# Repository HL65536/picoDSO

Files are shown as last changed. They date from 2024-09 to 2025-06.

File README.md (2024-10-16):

# picoDSO
================

**Open-Source Oscilloscope based on the Raspberry Pi Pico**

## Project Status
---------------

The minimum viable product is ready, and development of new features is 
ongoing. Updates will be published regularly, although the pace may be 
slow.

## Key Features
--------------

* **Flexible Data Acquisition**: Use either the internal ADC(s) of the 
Raspberry Pi Pico to measure up to ~2MSa/s or 1-2 faster external ADCs 
(requires a custom PCB) for >50MSa/s at 8 bit.
* **Optional PCB**: The project can be built on a breadboard or with an 
optional PCB for easier assembly and improved performance.
* **Display Options**: Supports both SSD1306 and ST7789 displays, with 
potential support for more in the future.

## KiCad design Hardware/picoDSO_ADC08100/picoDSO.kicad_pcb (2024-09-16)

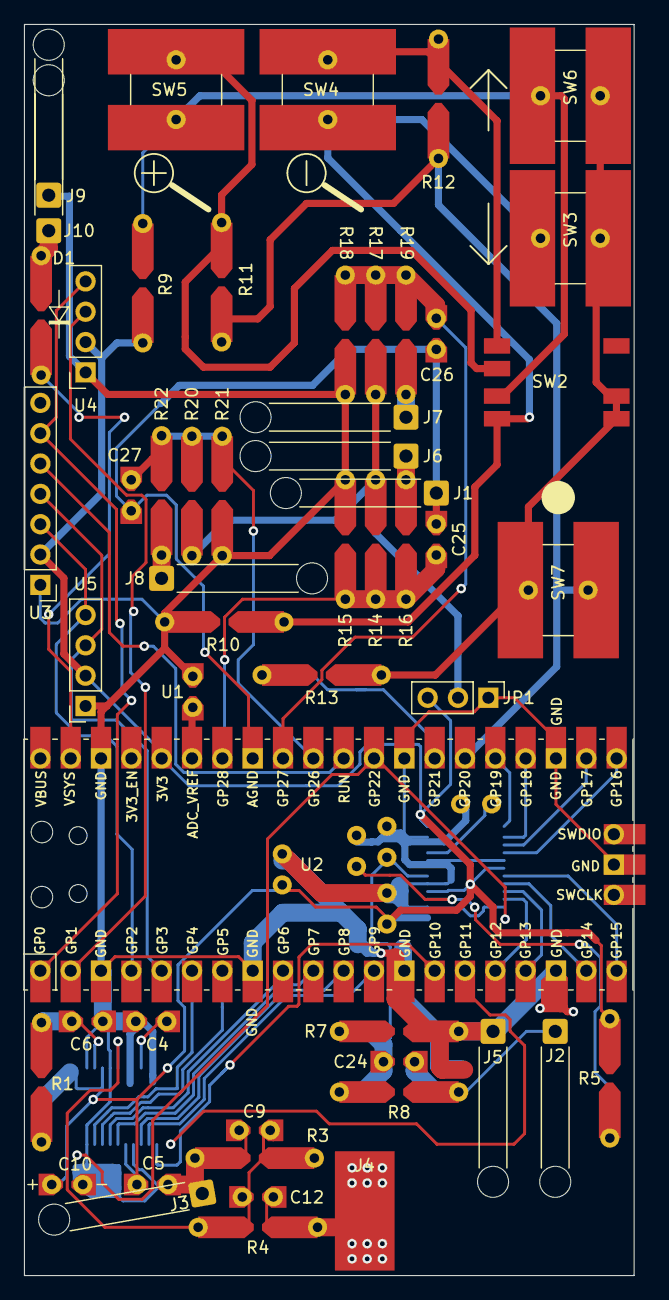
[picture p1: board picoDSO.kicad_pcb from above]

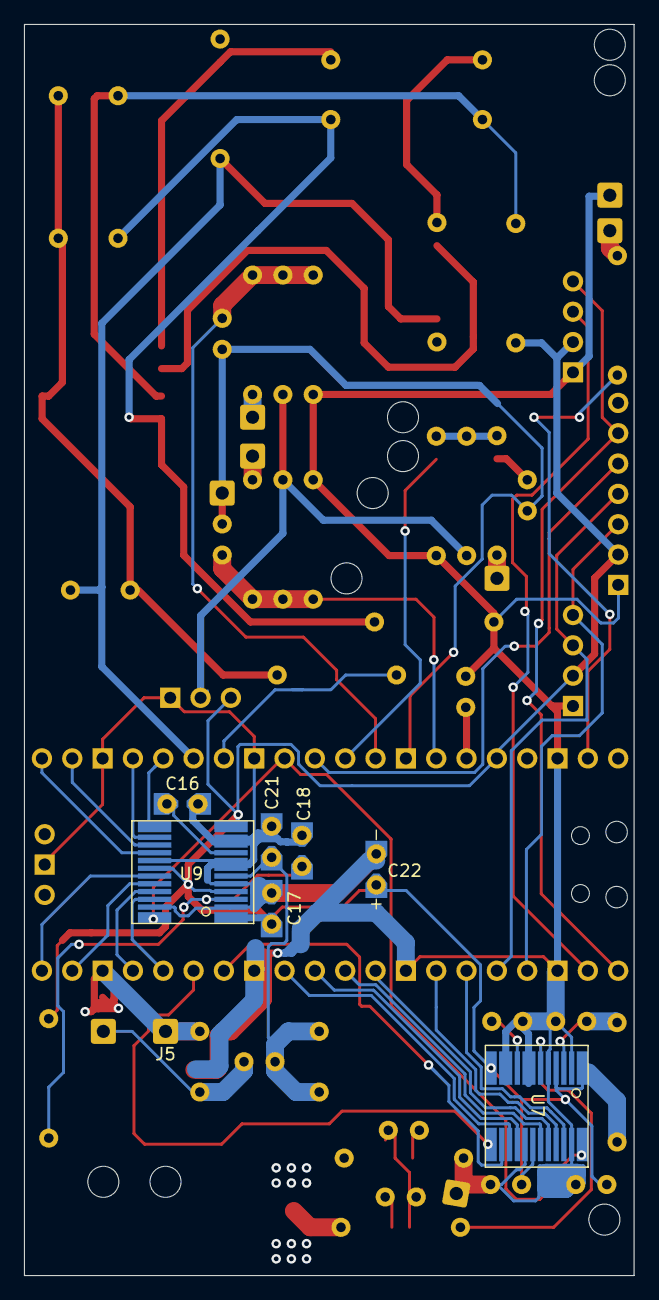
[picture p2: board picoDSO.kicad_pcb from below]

Board: 2 copper layers, 51.1 x 104.8 mm, 60 parts (7 on the bottom side), 50 nets.

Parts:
C4, C5, C6, C16, C17, C18: 100nF; universalMixed
C9, C21: Cdiv_bot; universalMixed
C10, C22: C_Polarized; universalMixedElectrolyticCap
C12, C24: Cdiv_top; universalMixed
C25, C26, C27: 68pF; universalMixed
D1: D_Schottky; universalMixedDiode
J1: internalADC_GND; SolderWire-0.5sqmm_1x01_D0.9mm_OD2.1mm_Relief
J2: chip1_probe+; SolderWire-0.5sqmm_1x01_D0.9mm_OD2.1mm_Relief
J3, J5: probeGND; SolderWire-0.5sqmm_1x01_D0.9mm_OD2.1mm_Relief
J4: chip0_probe+; SolderWirePad_1x01_SMD_5x10mm
J6, J7, J8: probeConnector; SolderWire-0.5sqmm_1x01_D0.9mm_OD2.1mm_Relief
J9: bat_GND; SolderWire-0.5sqmm_1x01_D0.9mm_OD2.1mm_Relief
J10: bat+; SolderWire-0.5sqmm_1x01_D0.9mm_OD2.1mm_Relief
JP1: internalADC_rangeselJumper; PinHeader_1x03_P2.54mm_Vertical
R1, R5: R; universalMixedLong
R3, R7: Rdiv_bot; universalMixedLong
R4, R8: Rdiv_top; universalMixedLong
R9, R10: 470; universalMixedLong
R11, R12: 4.7k; universalMixedLong
R13: 1k; universalMixedLong
R14, R15, R17, R18, R20, R21: 22k; universalMixedLong
R16, R19, R22: 100k; universalMixedLong
SW2: JoystickSwitch
SW3: dir2_alt; universalButton
SW4: dir4_alt; universalButton
SW5: dir3_alt; universalButton
SW6: dir1_alt; universalButton
SW7: button; universalButton
U1: optional_externalVREF; universalMixed
U2: Pico; RPi_Pico_SMD_TH
U3: ST7789; PinHeader_1x07_P2.54mm_Vertical
U4: SSD1306_Display1; PinSocket_1x04_P2.54mm_Vertical
U5: SSD1306_Display2; PinSocket_1x04_P2.54mm_Vertical
U7, U9: ADC08060; TSSOP-24 hand solder

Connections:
+3V3: C5.1, C10.1, C17.1, C22.1, JP1.3 (B), R1.2, R5.2, R9.1, U2.36 (3V3), U3.2 (VCC), U4.2 (VCC), U5.2 (VCC), U7.1 (AVDD), U7.4 (AVDD), U7.12 (AVDD), U7.18 (DVDD), U9.1 (AVDD), U9.4 (AVDD), U9.12 (AVDD), U9.18 (DVDD)
+BATT: D1.2 (A), J10.1
/ADC_chip0/clk: U2.29 (GPIO22), U7.24 (CLK), U9.24 (CLK)
/ADC_chip0/p0: U2.6 (GPIO4), U7.22 (D7)
/ADC_chip0/p1: U2.7 (GPIO5), U7.21 (D6)
/ADC_chip0/p2: U2.9 (GPIO6), U7.20 (D5)
/ADC_chip0/p3: U2.10 (GPIO7), U7.19 (D4)
/ADC_chip0/p4: U2.11 (GPIO8), U7.16 (D3)
/ADC_chip0/p5: U2.12 (GPIO9), U7.15 (D2)
/ADC_chip0/p6: U2.14 (GPIO10), U7.14 (D1)
/ADC_chip0/p7: U2.15 (GPIO11), U7.13 (D0)
/ADC_chip0/probe+: C12.1, J4.1, R4.1
/ADC_chip1/p0: U2.16 (GPIO12), U9.22 (D7)
/ADC_chip1/p1: U2.17 (GPIO13), U9.21 (D6)
/ADC_chip1/p2: U2.19 (GPIO14), U9.20 (D5)
/ADC_chip1/p3: U2.20 (GPIO15), U9.19 (D4)
/ADC_chip1/p4: U2.21 (GPIO16), U9.16 (D3)
/ADC_chip1/p5: U2.22 (GPIO17), U9.15 (D2)
/ADC_chip1/p6: U2.24 (GPIO18), U9.14 (D1)
/ADC_chip1/p7: U2.25 (GPIO19), U9.13 (D0)
/ADC_chip1/probe+: C24.1, J2.1, R8.1
/internalADCinput0/ADCpin: C27.1, R20.2, R21.1, R22.2, U2.31 (GPIO26_ADC0)
/internalADCinput1/ADCpin: C26.1, R17.2, R18.1, R19.2, U2.32 (GPIO27_ADC1)
/internalADCinput2/ADCpin: C25.1, R14.2, R15.1, R16.2, U2.34 (GPIO28_ADC2)
/navButtons/pin1: R13.1, U2.27 (GPIO21)
/navButtons/pin2: R11.2, R12.1, SW7.2, U2.26 (GPIO20)
GND: C4.2, C5.2, C6.2, C9.2, C10.2, C16.2, C17.2, C18.2, C21.2, C22.2, J3.1, J5.1, J9.1, JP1.1 (A), R3.2, R7.2, R10.2, R15.2, R18.2, R21.2, U1.2 (A), U2.3 (GND), U2.8 (GND), U2.13 (GND), U2.18 (GND), U2.23 (GND), U2.28 (GND), U2.38 (GND), U2.42 (GND), U3.1 (GND), U4.1 (GND), U5.1 (GND), U7.2 (AGND), U7.5 (AGND), U7.7 (VIN_GND), U7.8 (DGND), U7.10 (VRB), U7.11 (AGND), U7.17 (DGND), U7.23 (PWR_DWN), U9.2 (AGND), U9.5 (AGND), U9.7 (VIN_GND), U9.8 (DGND), U9.10 (VRB), U9.11 (AGND), U9.17 (DGND), U9.23 (PWR_DWN)
GNDA: C25.2, C26.2, C27.2, J1.1, U2.33 (AGND)
unnamed: C4.1, U7.9 (VRB)
unnamed: C6.1, R1.1, U7.3 (VRT)
unnamed: C9.1, C12.2, R3.1, R4.2, U7.6 (AIN)
unnamed: C16.1, U9.9 (VRB)
unnamed: C18.1, R5.1, U9.3 (VRT)
unnamed: C21.1, C24.2, R7.1, R8.2, U9.6 (AIN)
unnamed: D1.1 (K), U2.39 (VSYS)
unnamed: J6.1, R16.1
unnamed: J7.1, R19.1
unnamed: J8.1, R22.1
unnamed: R9.2, SW2.3 (1&3), SW5.1, SW6.1
unnamed: R10.1, SW2.4 (2&4), SW3.1, SW4.1
unnamed: R11.1, SW2.2 (dir3), SW5.2
unnamed: R12.2, SW2.1 (dir4), SW4.2
unnamed: R13.2, SW2.5 (dir2), SW2.6 (dir1), SW3.2, SW6.2, SW7.1
unnamed: U1.1 (K), U2.35 (ADC_VREF)
unnamed: U2.1 (GPIO0), U3.6 (DC), U4.4 (SDA)
unnamed: U2.2 (GPIO1), U4.3 (SCL)
unnamed: U2.4 (GPIO2), U3.3 (CLK), U5.4 (SDA)
unnamed: U2.5 (GPIO3), U3.4 (DAT), U5.3 (SCL)
unnamed: U2.30 (RUN), U3.5 (RES)
internalADCrangeSel: JP1.2 (C), R14.1, R17.1, R20.1

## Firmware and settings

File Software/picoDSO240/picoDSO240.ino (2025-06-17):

#include "rp2040Tools.h"
#include "EmbedUI.h"
#include "metric.h"
#include "oscilloscopeUtils.h"
#include "joystickButtons.h"
#include "pioRecorderDynamic.h"
#include "DisplayST7789_framebuf_2bit.h"


#define DISPLAY_WHITE 3
#define DISPLAY_COLOR1 1
#define DISPLAY_COLOR2 2
#define DISPLAY_BLACK 0

constexpr i32 highestIndexADCclock = 5;
enum ADCclock : i32
{
    clock250kSa = 0,
    clock500kSa = 1,
    clock1MSa = 2,
    clock2MSa = highestIndexADCclock - 2,
    clock2_5MSa = highestIndexADCclock - 1,
    clock3MSa = highestIndexADCclock
};
u32 clkSelectionsExt[] = {
    [0] = 40000,//24000,
    [1] = 80000,//48000,
    [2] = 120000,//96000,
    [highestIndexADCclock - 2] = 160000,//96000 * 2,
    [highestIndexADCclock - 1] = 200000,//9600 * 25,
    [highestIndexADCclock] = 240000//96000 * 3
    };

u32 clkSelectionsInt[] = {
    [0] = 24000,
    [1] = 48000,
    [2] = 96000,
    [highestIndexADCclock - 2] = 96000 * 2,
    [highestIndexADCclock - 1] = 9600 * 25,
    [highestIndexADCclock] = 96000 * 3
    };
//DisplayST7789_2bit display1(21,20,19,18,17,16,22,20);//breadboard version
DisplayST7789_2bit display1(0,17,3,2,-1,-1,-1,16);//PCB version 1.0 with only ADC chip 0
DisplayCommon &displayMenu = display1;
DisplayCommon &displayGraph = display1;
Adafruit_GFX &gfxMenu = display1.getGFX();
Adafruit_GFX &gfxGraph = display1.getGFX();

//JoystickButtons buts(1,0,2);//breadboard version
JoystickButtons buts(20,21);//PCB version 1.0


/*const String settingADCclockString[] = {"speed:\n"
                                        "160 kSa/s\n"
                                        "250 kSa/s\n"
                                        "500 kSa/s\n"
                                        "  2 MSa/s\n"
                                        "2.5 MSa/s\n"
                                        "  3 MSa/s"};
SettingEnum settingADCclock(settingADCclockString);*/
#define GRAPH_HEIGHT 128
#define GRAPH_WIDTH 240
#define GRAPH_HEIGHT_OFFSET 112

#define DATABUF_SIZE 200000l

Recording recording;//for now only one single recording is saved at a time, may be changed in the future
volatile bool useExternal=true;
volatile i32 captureIndex=-1;

volatile u8 channelCount=1;

bool startScreen = true;
bool onlyPositiveVoltageRange;
bool noInputStage=false;

u16 channelColors[]=//size must be at least equal to channelCount
{
    DISPLAY_COLOR1,
    DISPLAY_COLOR2
};

ADCclock ADCclockSelection = clock1MSa;

u32 clkWanted;

u32 adcClkDivInfo=4;//96 for internal ADC, auto-set later!

void settingsScreenLoop()
{
    displayMenu.startDrawing(1);
    buts.evaluate();
    if(buts.getButtonEvent())
    {
        recording.allocateSpace(DATABUF_SIZE,channelCount);
        startScreen=false;
    }
    else
    {
        ADCclockSelection = (ADCclock)(((i32)ADCclockSelection) + buts.getUpEvents());
        if (ADCclockSelection > highestIndexADCclock)
        {
            ADCclockSelection = (ADCclock)0;
        }
        if (ADCclockSelection < 0)
        {
            ADCclockSelection = (ADCclock)highestIndexADCclock;
        }
        gfxMenu.print("speed: ");
        adcClkDivInfo = useExternal?4:96;
        u32 kSa = clkSelectionsExt[ADCclockSelection] / adcClkDivInfo;
        gfxMenu.print(kSa);
        gfxMenu.println("kSa/s");

        gfxMenu.println();
        gfxMenu.println("press .");
        gfxMenu.println("  to");
        gfxMenu.println("confirm");
        gfxMenu.println("settings");

        displayMenu.endDrawing();
    }
    
}
void setup()
{
    pinMode(LED_BUILTIN, OUTPUT);
    display1.Init();
    display1.setRotation(2);
    while(startScreen)
    {
        settingsScreenLoop();
    }
}
u8 highFor2Vref=14;
u8 refSelLowIsInternal=15;
void setup1()//2nd core
{
    pinMode(LED_BUILTIN, OUTPUT);

    pinMode(A0, INPUT);
    pinMode(A1, INPUT);
    pinMode(A2, INPUT);

    pinMode(highFor2Vref,OUTPUT);
    digitalWrite(highFor2Vref,HIGH);

    pinMode(refSelLowIsInternal, OUTPUT);
    digitalWrite(refSelLowIsInternal, LOW);

    while(startScreen)
    {
        delay(1);
    }

    clkWanted = clkSelectionsExt[ADCclockSelection];
    if (ADCclockSelection == clock500kSa)
    {
        setCPUClockspeed(133000); // max speed by specs
        delay(100);
    }
    else
    {
        if (clkWanted > 200000)
        {
            setCoreVoltageOffset(4);
            delay(100);
        }
        else if (clkWanted > 180000)
        {
            setCoreVoltageOffset(2);
            delay(100);
        }
        setADCclockBoundToCPUclock(true); // ADC now at adcClock/96000 MSa/s
        setCPUClockspeed(clkWanted);
    }
}

float scaleTime = 1024;
u32 discardSamples = 64;// don't show the first 64 samples to avoid showing ADC startup glitches
u32 startPos = discardSamples;

void printPIOdebugInfo()
{
    gfxMenu.print("PIO rx FIFO lvl: ");
    gfxMenu.print(pio_sm_get_rx_fifo_level(pio0, 0));
    gfxMenu.print("; TX: ");
    gfxMenu.print(pio_sm_get_tx_fifo_level(pio0, 0));
    gfxMenu.print("; stall: ");
    gfxMenu.println(pio_sm_is_exec_stalled(pio0, 0));
    gfxMenu.print("PIO PC: ");
    for(u32 i=0;i<8;i++)
    {
        gfxMenu.print(pio_sm_get_pc(pio0, 0));
        gfxMenu.print('|');
    }
    gfxMenu.println();
}

float convertVoltage(u16 rawValue,bool onlyPositive=true)
{
    float ret=rawValue;
    if (recording.is16bit())
    {
        ret /= 4096.0f;//only supported ADC with 16 bit data length is currently the internal 12-bit ADC
    }
    else
    {
        ret /= 256.0f;
    }
    if(!onlyPositive)
    {
        ret-=0.5f;
    }
    ret *= 15;//(3.00f * 11.0f);//3.27V default reference, 11:1 voltage divider
    return ret;
}
bool err=false;
bool unconv=false;
volatile i8 samplesInFIFO = 0;
float tuningFactor=1;
LoopTimer lt;


u16 instr0;
u16 instr1;
u32 instrS;

void loop()
{
    float time=lt.tick();
    
    u32 dataLength = recording.getNumSamples()-discardSamples;
    if(recording.getNumSamples()<discardSamples+1)
    {
        delay(1);
        return;
    }
    //dataToDisplay[0]^=65536/4;//fake an unconverged sample in 1/2 of the frames
    buts.evaluate();
    i8 upDir=buts.getUpEvents();
    if(upDir>0)
    {
        scaleTime/=2;
    }
    else if(upDir<0)
    {
        scaleTime *= 2;
    }
    i8 rightDir=buts.getRightEvents();
    startPos += scaleTime * 32 * rightDir; // auto-protects against underflow
    if (startPos >= dataLength)
    {
        startPos = dataLength - 1;
    }
    if (startPos < discardSamples)
    {
        startPos = discardSamples;
    }

    displayMenu.startDrawing(1);

    BandwidthExtenderRC bwExt(((1000000.0f*adcClkDivInfo) / clkSelectionsExt[ADCclockSelection]), 26, 10, tuningFactor);//224pF (theoret. 236pF) for P11, 84pF für Bernd, 26pF for P11.2
    u16 voltMax = 0;
    u16 voltMin = 4096;
    for (u32 i = 0; i < dataLength; i++) // find highest + lowest measured voltage
    {
        u16 rawVal = recording.readIndex(i);//get the value from memory only once, as this prevents a previous bug of the value being changed by the DMA in between the statements below
        u16 rawValMasked = rawVal & 4095; //filter out unconverged flag
        if (rawVal != rawValMasked)
        {
            unconv = true;
        }
        if (rawValMasked < voltMin)
        {
            voltMin = rawValMasked;
        }
        if (rawValMasked > voltMax)
        {
            voltMax = rawValMasked;
        }
    }
    float scaleAdd = -float(voltMin);
    float scaleDiv = float(voltMax - voltMin);
    if (scaleDiv < 1)
    {
        scaleDiv = 1; //prevent /0
    }
    GraphDisplaySpace gds(GRAPH_HEIGHT, GRAPH_WIDTH);
    //i32 lastIndex = -1;
    gfxGraph.fillScreen(ST77XX_BLACK); // Fill screen with black color
    gfxGraph.setCursor(0, 0);          // Set cursor to top-left corner;

    for (i32 i = 0; i < GRAPH_WIDTH; i++)
    {
        i32 index = i * scaleTime + startPos;
        if (index < 0)
        {
            continue;
        }
        if (index >= dataLength)
        {
            continue;
        }
        for (u8 ch = 0; ch < channelCount; ch++)
        {
            u16 rawVal = recording.readIndex(index,ch);
            float voltage = rawVal & 4095; // filter out unconverged flag
                /*if (index == lastIndex)
                {
                    voltage = lastVoltage;
                }
                else if (scaleTime<5)
                {
                    u32 increments = index - lastIndex;
                    i32 bwX = ~(i32(0));
                    for (u32 i = 0; i < increments; i++)
                    {
                        bwX = bwExt.calcStep(dataToDisplay[lastIndex + i] & 4095);
                    }
                    if (bwX != ~(i32(0)))
                    {
                        voltage = bwX / 65536.0f;
                    }
                }
                lastVoltage = voltage;*/
            voltage += scaleAdd;
            voltage /= scaleDiv;
            u16 pixY = gds.toY(voltage);
            //u16 color = channelColors[ch];
            if (pixY == -1)
            {
                continue;
            }
            if (rawVal >= 4096)
            {
                gfxGraph.drawPixel(i, pixY - 1, DISPLAY_COLOR1); // mark unconverged sample
                gfxGraph.drawPixel(i, pixY + 1, DISPLAY_COLOR1);
            }
            gfxGraph.drawPixel(i, pixY + GRAPH_HEIGHT_OFFSET, DISPLAY_COLOR2);
        }
    }
        
    if (captureIndex == -1)
    {
        gfxMenu.println("Press . for capture");
    }
    else
    {
        gfxMenu.print(captureIndex);
        gfxMenu.print('/');
        gfxMenu.println(recording.is16bit()? DATABUF_SIZE/2:DATABUF_SIZE);
    }
    gfxMenu.print("top:    ");
    metricPrintln(convertVoltage(voltMax, onlyPositiveVoltageRange), 'V', gfxMenu, 4);
    gfxMenu.print("bottom: ");
    metricPrintln(convertVoltage(voltMin, onlyPositiveVoltageRange), 'V', gfxMenu, 4);
    gfxMenu.print(startPos);
    gfxMenu.print("; ");
    gfxMenu.print("timespan: ");
    float timePerSample = (adcClkDivInfo* 1000.0f/clkSelectionsExt[ADCclockSelection]) / 1000.0f / 1000.0f;
    metricPrintln(timePerSample * scaleTime * GRAPH_WIDTH, 's', gfxMenu, 4);
    if (err)
    {
        gfxMenu.println("error capturing");
    }
    if (unconv)
    {
        gfxMenu.println("unconverged samples");
    }
    gfxMenu.print("raw min: ");
    gfxMenu.println(voltMin);
    gfxMenu.print("raw max: ");
    gfxMenu.println(voltMax);
    gfxMenu.print("tuning: ");
    gfxMenu.println(tuningFactor);
    gfxMenu.print("clk: ");
    gfxMenu.println(getCPUClockspeed() / 1000000.0f);
    printPIOdebugInfo();
    metricPrintln(time, 's', gfxMenu);
    gfxMenu.print(instr0, HEX);
    gfxMenu.print(' ');
    gfxMenu.print(instr1, HEX);
    gfxMenu.print(' ');
    gfxMenu.println(instrS);
    // displayMenu.print("corrMtp: ");
    // displayMenu.println(bwExt.correctionMultiplier);

    // displayGraph.display();
    displayMenu.endDrawing();

}
bool capturePIOcombined(u8 startPin, u8 clkPin)
{
    digitalWrite(LED_BUILTIN,HIGH);
    u8 dataBits = 8*channelCount;
    for (u8 i = startPin; i < startPin + dataBits; i++)
    {
        pinMode(i, INPUT);
    }
    captureIndex = 0;
    PIO pio = pio0;
    PioInstance pioI(pio);
    
    DMAinstance dmaI;
    dmaI.setTransferBitSize(channelCount * 8);
    dmaI.targetRAMbuffer(recording.is16bit()?(void *)(recording.dataPtr16):(void *)(recording.dataPtr8), DATABUF_SIZE);
    dmaI.sourceFromPIO(false, 0);
    dmaI.setHighPriority();

    PioProgram prog;
    fillRecordingProgram(prog,false,2,2);
    pioI.setProgram(prog);

    pioI.sm0.clearFIFOs();
    pioI.sm0.claim();
    
    pioI.sm0.setPindirs(clkPin, 1, true);
    pio_gpio_init(pio, clkPin); // TODO ?
    pioI.sm0.setPindirs(startPin, 8, false);
    
    captureIndex++;
    
    pioI.sm0.setAutomaticLoopLineNumbers(0,prog.instructions.size()-1);
    pioI.sm0.setSidesetPins(clkPin,1,false,false);
    pioI.sm0.setIsrPush(false,true,8);
    pioI.sm0.setFirstInPin(startPin);
    pioI.sm0.setClockDivider(1);
    pioI.sm0.setBothFIFOsRX();
    pioI.sm0.setStartInstruction(0);

    captureIndex++;
    dmaI.start();

    pioI.sm0.startRunning();


    captureIndex++;
    dmaI.waitUntilFinished();
    captureIndex++;

    pioI.sm0.stopRunning();

    pioI.clearInstructionMemory();
    pioI.sm0.unclaim();

    captureIndex = DATABUF_SIZE;
    return true;
}
/*
bool captureDMA(u8 pin=ADC1)
{
    unconv=false;
    captureIndex = -5;
    prepareADCforDMA(pin, sizeof(data[0])==1,true);
    captureIndex = -4;
    DMAinstance dmaI;
    dmaI.setTransferBitSize(sizeof(data[0])*8);
    dmaI.targetRAMbuffer(data,DATABUF_SIZE);
    dmaI.sourceFromADCfifo();
    dmaI.setHighPriority();
    dmaI.start();
    captureIndex = -2;
    startFreeRunningMode();
    //delay(1); //Microseconds(20);
    samplesInFIFO = adc_fifo_get_level();
    //dmaI.start();
    captureIndex = 0;
    dmaI.waitUntilFinished();
    captureIndex = 1;
    bool missed = stopFreeRunningMode();
    captureIndex = 3;
    if (missed)
    {
        captureIndex = 8;
        stopFreeRunningMode();
        return false;
    }
    captureIndex = DATABUF_SIZE;
    stopFreeRunningMode();//do not fuse with the one inside the if, it clears flag needed for the if
    return true;
}*/

void loop1()//2nd core
{
    if(buts.getButtonEvent())
    {
        setCPUClockspeed(clkWanted);
        delay(20);
        onlyPositiveVoltageRange = true;//analogRead(A0) < 256;
        //PCB version: pin 4 is LSB for external ADC, pin 22 is clk for external ADC
        err = !capturePIOcombined(4,22);//6,5);//!captureDMA(ADC1); // captureRapid(ADC2);
        setCPUClockspeed(200000);
        //err = !captureRapidMulti(2);aDS
    }
    else
    {
        delay(10);
    }
}

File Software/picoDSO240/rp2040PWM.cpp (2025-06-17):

#include "rp2040PWM.h"
#include "hardware/pwm.h"
#include "hardware/regs/pwm.h"

u8 syncPWMs = 0;

void PWMslice::setClockDivider(float div)
{
    pwm_set_clkdiv(sliceNum, div);
}

void PWMslice::setCounterMax(u16 periodMinus1)
{
    pwm_set_wrap(sliceNum,periodMinus1);
}

void PWMslice::setPhaseCorrect(bool phaseCorrect)
{
    pwm_set_phase_correct(sliceNum,phaseCorrect);
}

void PWMslice::setOutputPolarities(bool invertEvenPin, bool invertOddPin)
{
    pwm_set_output_polarity(sliceNum,invertEvenPin,invertOddPin);
}

void PWMslice::setEvenPinInverted(bool inverted)
{
    u32 changemask = 4;// 0100
    u32 keepmask = ~changemask;
    if(!inverted)
    {
        changemask = 0;
    }
    pwm_hw->slice[sliceNum].csr = changemask | (keepmask&(pwm_hw->slice[sliceNum].csr));
}

void PWMslice::setOddPinInverted(bool inverted)
{
    u32 changemask = 8;// 1000
    u32 keepmask = ~changemask;
    if (!inverted)
    {
        changemask = 0;
    }
    pwm_hw->slice[sliceNum].csr = changemask | (keepmask & (pwm_hw->slice[sliceNum].csr));
}

void PWMslice::setPinInverted(u8 pin, bool inverted)
{
    if((pin%2)==0)
    {
        setEvenPinInverted(inverted);
    }
    else
    {
        setOddPinInverted(inverted);
    }
}

void PWMslice::setCounterValue(u16 val)
{
    pwm_set_counter(sliceNum,val);
}

void PWMslice::start()
{
    pwm_set_enabled(sliceNum,true);
}

void PWMslice::freeze()
{
    pwm_set_enabled(sliceNum, false);
}

void PWMslice::stopAt0()
{
    volatile u32 &bothDuty = refToBothDuty();
    u32 prevDuty = bothDuty;
    bothDuty = 0;

    volatile u32 &top = refToCounterMax();

    volatile u32 &rawClkDiv = refToRawClkDivRegister();
    u32 prevClkDiv = rawClkDiv;
    rawClkDiv=0x10;// set to a divider of 1

    volatile u32 &counter = refToRawCounterRegister();
    if(top>4)
    {
        counter = top - 2;//reduce the clock cycles until reaching TOP to reach it in <1µs
    }
    delayMicroseconds(1); // assuming a clockspeed >= 4MHz, this makes sure the counter has reached TOP at least once, updating the pin state to off
    freeze();

    // restore values
    bothDuty = prevDuty;
    rawClkDiv = prevClkDiv;
}

void PWMslice::stopAt1()
{
    volatile u32 &top = refToCounterMax();
    u16 prevTop = top;

    volatile u32 &bothDuty = refToBothDuty();
    u32 prevDuty = bothDuty;
    bothDuty = 0xFFFFFFFF; // set both to maximum values

    volatile u32 &rawClkDiv = refToRawClkDivRegister();
    u32 prevClkDiv = rawClkDiv;
    rawClkDiv = 0x10; // set to a divider of 1 to speed things up

    volatile u32 &counter = refToRawCounterRegister();

    if(top==0xFFFF)//cannot reach 100% duty in this case
    {
        top--;
    }
    if (top > 4)
    {
        counter = top - 2; // reduce the clock cycles until reaching TOP to reach it in <1µs
    }
    delayMicroseconds(1); // assuming a clockspeed >= 4MHz, this makes sure the counter has reached TOP at least once, updating the pin state to off
    freeze();

    // restore values
    bothDuty = prevDuty;
    rawClkDiv = prevClkDiv;
    top=prevTop;
}

void PWMslice::incrementCounter()
{
    pwm_advance_count(sliceNum);
}

void PWMslice::decrementCounter()
{
    pwm_retard_count(sliceNum);
}

void PWMslice::setEvenDuty(u16 val)
{
    pwm_set_chan_level(sliceNum, 0, val);
}

void PWMslice::setOddDuty(u16 val)
{
    pwm_set_chan_level(sliceNum, 1, val);
}

void PWMslice::setPinDuty(u8 pin, u16 val)
{
    pwm_set_gpio_level(pin,val);
}

union rp2040PWMhelperUnion
{
    volatile u32 reg;
    volatile u16 vals[2];
};

volatile u16 &PWMslice::refToEvenPinDuty()
{
    volatile rp2040PWMhelperUnion *helperUnion = (rp2040PWMhelperUnion *)(&(pwm_hw->slice[sliceNum].cc));
    return helperUnion->vals[0];
}

volatile u16 &PWMslice::refToOddPinDuty()
{
    volatile rp2040PWMhelperUnion *helperUnion = (rp2040PWMhelperUnion *)(&(pwm_hw->slice[sliceNum].cc));
    return helperUnion->vals[1];
}

volatile u32 &PWMslice::refToBothDuty()
{
    return pwm_hw->slice[sliceNum].cc;
}

volatile u16 &PWMslice::refToPinDuty(u8 pin)
{
    if((pin%2)==0)
    {
        return refToEvenPinDuty();
    }
    else
    {
        return refToOddPinDuty();
    }
}

volatile u32 &PWMslice::refToRawClkDivRegister()
{
    return pwm_hw->slice[sliceNum].div;
}

volatile u32 &PWMslice::refToRawCounterRegister()
{
    return pwm_hw->slice[sliceNum].ctr;
}

volatile u32 &PWMslice::refToCounterMax()
{
    return pwm_hw->slice[sliceNum].top;
}

void PWMslice::simultaneouslyEnable(bool startAllCalledSlicesNow)
{
    syncPWMs |= (1<<sliceNum);
    if(startAllCalledSlicesNow)
    {
        pwm_set_mask_enabled(syncPWMs);
        syncPWMs = 0;
    }
}

u32 PWMslice::getRawDreqID()
{
    return pwm_get_dreq(sliceNum);
}

PWMslice::PWMslice(u8 pin, bool initPins):
sliceNum(pwm_gpio_to_slice_num(pin))
{
    if(initPins)
    {
        gpio_set_function(pin, GPIO_FUNC_PWM);
    }
}

PWMslice::PWMslice(u8 evenPin, u8 oddPin, bool initPins):
sliceNum(pwm_gpio_to_slice_num(evenPin))
{
    if (initPins)
    {
        gpio_set_function(evenPin, GPIO_FUNC_PWM);
        gpio_set_function(oddPin, GPIO_FUNC_PWM);
    }
}

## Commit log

2024-09-16 Added KiCad files
    KiCad files for ADC08100 family and ADS830E family chips. Generic board with multiple parts options.
    [ADC_chip.kicad_sch, navButtons.kicad_sch, picoDSO.kicad_pcb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]
2025-06-17 added v0.1.0 of oscilloscope firmware
    It should have been there along with the initial hardware version (oops). Uses a fixed configuration for single external ADC chip (default 60MHz).
    [DisplayCommon.cpp, DisplaySSD1306.cpp, DisplayST7789.cpp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]
2025-06-17 Fixed voltage scale, refactored code
    The displayed voltage scaling for the graph is now correct
    PIO code is now changed to new, cleaner system using wrapper
    Use recording class instead of raw arrays for data acquisition and storage
    Files for future 3-bit framebuffer added
    [DisplayST7789_framebuf_3bit.cpp, picoDSO240.ino]
